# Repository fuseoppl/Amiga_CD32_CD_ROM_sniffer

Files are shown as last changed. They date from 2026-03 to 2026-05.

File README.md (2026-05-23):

# Amiga CD32 CD Drive sniffer and Track Display

* CD32 Akiko-CDROM IF command sniffer and track display
* Arduino pin 13 to Amiga CD32 IF_CLK
* Arduino pin 11 to Amiga CD32 IF_DATA
* Arduino pin  3 to Amiga CD32 IF_DIR
* Arduino GND    to Amiga CD32 GND
* Arduino pin  4 to Amiga CD32 RST via schottky diode, anode to CD32 RST
* The display must be with I2C communication!
* https://www.tztstore.com/goods/show-6267.html
* TZT 2.26 Inch 4PIN White OLED Screen Module IPS 1602 Character OLED Screen KS0066 Drive IC IIC Interface 5V For Arduino
* The display must be with I2C communication!

To work in display mode, leave this enabled:
#define LCDENABLE

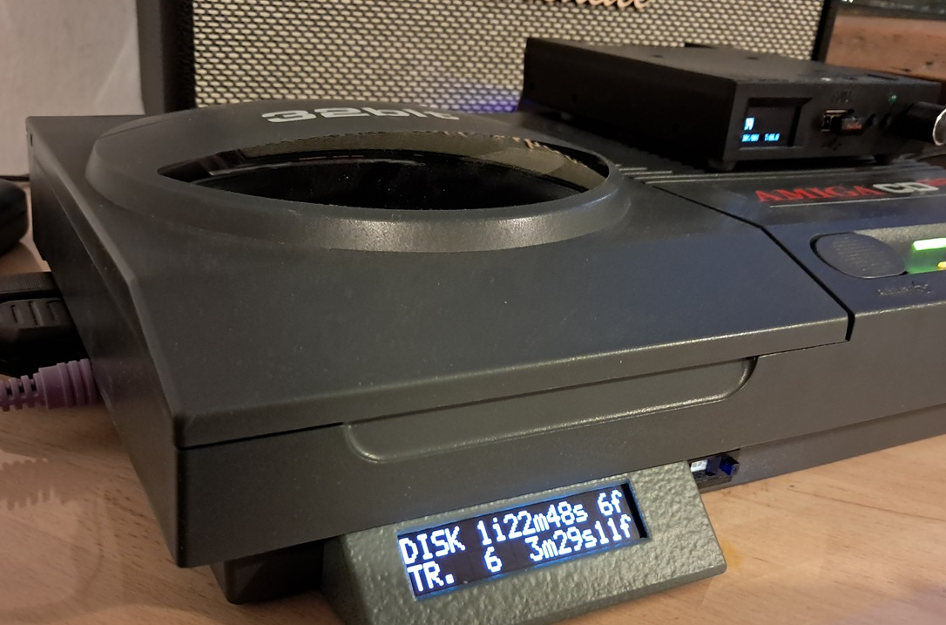
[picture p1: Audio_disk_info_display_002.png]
schema


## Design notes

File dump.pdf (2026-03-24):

TOC Information: | Audio CD Play Packets (first track)
LBA: 0 / 00:02:00 | 1 | 2 | 3 | 4 | 5 | 6 | 7 | 8 | 9 | 10 | 11 | 12 | 13 | 85 | 86 | Packets
Track | 01 | Audio | 03:27:31 | LBA: | 0 | 00:02:00 | 15

INITIALIZATION .

READ CONTENT .
Akiko | 26 | 36 | 46 | 56 | 66 | 76 | 86 | 96 | A6 | B6 | C6 | D6 | E6 | 36 | 46 | Low nibble always 0x6, High incrasing
Track | 02 | Audio | 03:29:34 | LBA: | 15556 | 03:29:31 | 0 | A | D9 | C9 | B9 | A9 | 99 | 89 | 79 | 69 | 59 | 49 | 39 | 29 | 19 | C9 | B9 | Checksum (2's complement)
Track | 03 | Audio | 04:23:03 | LBA: | 31265 | 06:58:65 | EA | A2

CD Drive

| | | | | | | | | | 26 | 36 | 46 | 56 | 66 | 76 | 86 | 96 | A6 | B6 | C6 | D6 | E6 | 36 | 46 | same as the first byte in the Akiko order
Track | 04 | Audio | 04:23:73 | LBA: | 50993 | 11:21:68 | N/A | | 6 | 2 | 2 | 2 | 2 | 2 | 2 | 2 | 2 | 2 | 2 | 2 | 2 | 2 | 2 | 2 | 2
Track | 05 | Audio | 03:33:04 | LBA: | 70791 | 15:45:66 | 27 | | A | 0 | 0 | 0 | 0 | 0 | 0 | 0 | 0 | 0 | 0 | 0 | 0 | 0 | 0 | 0 | 0 ?
Track | 06 | Audio | 04:00:17 | LBA: | 86770 | 19:18:70 | D8 | | 0 | 1 | 1 | 1 | 1 | 1 | 1 | 1 | 1 | 1 | 1 | 1 | 1 | 1 | 1 | 1 | 1 (WinUAE says: CtlAdr) ?
Track | 07 | Audio | 01:06:20 | LBA: | 104787 | 23:19:12 | 27 | | 1 | 1 | 1 | 1 | 1 | 1 | 1 | 1 | 1 | 1 | 1 | 1 | 1 | 1 | 1 | 1 | Track Nr
Track | 08 | Audio | 05:23:20 | LBA: | 109757 | 24:25:32 | 1 | | 0 | 1 | 1 | 1 | 1 | 1 | 1 | 1 | 1 | 1 | 1 | 1 | 1 | 1 | 1 | 1 | 1 (WinUAE says: Index) ?
Track | 09 | Audio | 04:34:08 | LBA: | 134002 | 29:48:52 | 43 C | 6 | 0 | 0 | 0 | 0 | 0 | 0 | 0 | 0 | 0 | 0 | 0 | 0 | 0 | 0 | 0 | Track.time.min (0-99)
Track | 10 | Audio | 04:25:60 | LBA: | 154560 | 34:22:60 | 48 H | 1 | 0 | 0 | 0 | 0 | 0 | 0 | 0 | 0 | 0 | 1 | 1 | 1 | 1 | 8 | 8 | Track.time.sec (0-59)
Track | 11 | Audio | 05:43:15 | LBA: | 174495 | 38:48:45 | 49 | I | 49 | 2 | 11 | 21 | 29 | 39 | 47 | 57 | 58 | 65 | 0 | 8 | 18 | 26 | 15 | 24 | Track.time.frame (0-75)
Track | 12 | Audio | 02:53:73 | LBA: | 200235 | 44:31:60 | 4E N | 42 | 0 | 0 | 0 | 0 | 0 | 0 | 0 | 0 | 0 | 0 | 0 | 0 | 0 | 0 | 0 | 0
Track | 13 | Audio | 05:09:04 | LBA: | 213283 | 47:25:58 | 4F O | 0 | 0 | 0 | 0 | 0 | 0 | 0 | 0 | 0 | 0 | 0 | 0 | 0 | 0 | 0 | 0 | Disk.time.min (0-99)
Track | 14 | Audio | 05:51:55 | LBA: | 236462 | 52:34:62 | 4E N | 19 | 2 | 2 | 2 | 2 | 2 | 2 | 2 | 2 | 2 | 3 | 3 | 3 | 3 | 10 | 10 | Disk.time.sec (0-59)
LeadOut (LBA: 262842 / 58:26:42) | 20 | 18 | 2 | 11 | 21 | 29 | 39 | 47 | 57 | 58 | 65 | 0 | 8 | 18 | 26 | 15 | 24 | Disk.time.frame (0-75)
| | | | | | | 20 | | 70 | 0 | 0 | 0 | 0 | 0 | 0 | 0 | 0 | 0 | 0 | 0 | 0 | 0 | 0 | 0 | 0
Track Information: | 4F 0 | 0 | 0 | 0 | 0 | 0 | 0 | 0 | 0 | 0 | 0 | 0 | 0 | 0 | 0 | 0 | 0 | 0
2D - | 0 | CE | A0 | 70 | 50 | 20 | F4 | C4 | B2 | 88 | 40 | 20 | F0 | C4 | 82 | 54 | Checksum (2's complement)
Track | 01 | LTSA: | 0 | LTS: | 15556 | 36 6 | BB
Track | 02 | LTSA: | 15556 | LTS: | 15709 | 35 5 | 65
Track | 03 | LTSA: | 31265 | LTS: | 19728 | 38 8 | 1 | Akiko to CD Drive
Track | 04 | LTSA: | 50993 | LTS: | 19798 | 2D - | 99 | Track number | A0=?, A1=Total Track number, A2=Total Disk Time
Track | 05 | LTSA: | 70791 | LTS: | 15979 | 32 2 | 6 | Strart time
Track | 06 | LTSA: | 86770 | LTS: | 18017 | 20 | A | Index ?
Track | 07 | LTSA: | 104787 | LTS: | 4970 | 32 2 | 0 | Checksum (2's complement)
Track | 08 | LTSA: | 109757 | LTS: | 24245 | 34 4 | 1 | Akiko order Checksum (2’s complement)
Track | 09 | LTSA: | 134002 | LTS: | 20558 | D4 | 0 | N/A = no ansfer from CD Drive
Track | 10 | LTSA: | 154560 | LTS: | 19935 | | 35 | | 6
Track | 11 | LTSA: | 174495 | LTS: | 25740 | 1 | 1 | SPI config for Arduino UNO
Track | 12 | LTSA: | 200235 | LTS: | 13048 | C9 | 49 | pinMode(MISO, OUTPUT);
Track | 13 | LTSA: | 213283 | LTS: | 23179 | N/A | 44 | // SPI on (MSTR = 0 so slave mode)
Track | 14 | LTSA: | 236462 | LTS: | 26380 | 44 | 0 | bitSet(SPCR, SPE);
0 | 19 | // SPI MODE 3
0 | 18 | bitSet(SPCR, CPOL);
0 | 70 | bitSet(SPCR, CPHA);
0 | 0 | // SPI LSB first
0 | 0 | bitSet(SPCR, DORD);
0 | B9 | // SPI interrupts on
3 | 75 | bitSet(SPCR, SPIE);
0 0
0 8A
0 6

### 0 A

| | | | | | | B8 | | 0
| | | | | | | 44 | | 1
| | | | | | | 1 | | 0
| | | | | | | BA | | 7
53 1
| | | | | | | AC | | 49
| | | | | | | 53 | | 45
| | | | | | | 29 | | 0
| | | | | | | 83 | | 23
| | | | | | | | | 19
| | | | | | | | | 12
| | | | | | | | | 0
| | | | | | | | | 0

A
85 1 79

6 A 0 1 0

7
1 49 46 0

23 19 12

0 0

9
95 0 6A

6 A 0 1 0

7
1 49 47 0

23 19 12

0 0

8
A5 1 59

6 A 0 1 0

8
1 49 48 0

24 25 32

0 0

D9

B5 0

4A6A01081

49 490

24 25

3200

D8
C51

396A01081

49 500

24 25

3200

D1
D50

2A6A01091

49 510

29 48

5200

87
E5

1
196A01091

49 520

29 48

5200

86

### F50A6A01091

49 530

29 48

5200

85
151

E96A010

101

49 540

34 22

6000

8A
250

DA

A 1 0

10
1 49 55 0

34 22 60

0 0

89
35 1 C9

6 A 0 1 0

10
1 49 56 0

34 22 60

0 0

88
45 0 BA

6 A 0 1 0

11
1 49 57 0

38 48 45

0 0

77
55 1 A9

A010

| 111

49 580

| 38 48
| 4500
| 76
| 650
| 9A6A010
| 111

49 590

| 38 48
| 4500
| 75
| 751
| 896A010
| 121

49 600

| 44 31
| 6000
| 5D
| 850 7A6

A

| 12
| 1 49 61 0
| 44 31 60
| 0 0
| 5C
| 95 1 69
| 6 A 0 1 0
| 12
| 1 49 62 0
| 44 31 60
| 0 0
| 5B
| A5 0 5A
| 6 A 0 1 0
| 13
| 1 49 63 0
| 47 25 58
| 0 0
| 6A
| B5 1 49
| 6 A

131

49 640

| 47 25
| 5800
| 69
| C50
| 3A6A010
| 131

49 650

| 47 25
| 5800
| 68
| D51
| 296A010
| 141

49 660

| 52 34
| 6200
| 42
| E50
| 1A6A0

49 67 0

52 34 62

0 0

41
F5 1 9

6 A 0 1 0

14
1 49 68 0

52 34 62

0 0

40
15 0 EA

6 A 0 1 0

A0
1 49 69 0

1
0 0 0 0

9A
25 1 D9

6 A 0 1

A0

70 0

1
0 0 0 0

93
35 0 CA

6 A 0 1 0

A0
1 49 71 0

1
0 0 0 0

92
45 1 B9

6 A 0 1 0

A1
1 49 72 0

14
0 0 0 0

7D
55 0 AA

6 A 0 1 0

A1

0
14
0 0 0 0

7C
65 1 99

6 A 0 1 0

A1
1 49 74 0

14
0 0 0 0

7B
75 0 8A

6 A 0 1 0

A2
1 50 0 0

58 26 42

0 0

3B
85 1 79

6 A 0 1 0

A2

58 26 42

0 0

3A
95 0 6A

6 A 0 1 0

A2
1 50 2 0

58 26 42

0 0

39
A5 1 59

6 A 0 1 0

1
1 50 3 0

0 2 0

0 0

97
B5 0 4A

6 A 0 1 0

1
1

4002000

96
C51

396A01011

505002000

95
D50

2A6A01021

50603

29
3100

38
E51

196A01021

50

31
0 0

37
F5 0 A

6 A 0 1 0

2
1 50 8 0

3 29 31

0 0

36
15 1 E9

6 A 0 1 0

3
1 50 9 0

6 58 65

0 0

CE
25 0 DA

6 A 0 1 0

3
1 50 10

0 0

C7
35 1 C9

6 A 0 1 0

3
1 50 11 0

6 58 65

0 0

C6
45 0 BA

6 A 0 1 0

4
1 50 12 0

11 21 68

0 0

ED
55 1 A9

6 A 0 1 0

4
1 50 13 0

0
EC
65 0 9A

6 A 0 1 0

4
1 50 14 0

11 21 68

0 0

EB
75 1 89

6 A 0 1 0

5
1 50 15 0

15 45 66

0 0

C3
85 0 7A

92
6D
92 3

6A
A5 0 5A

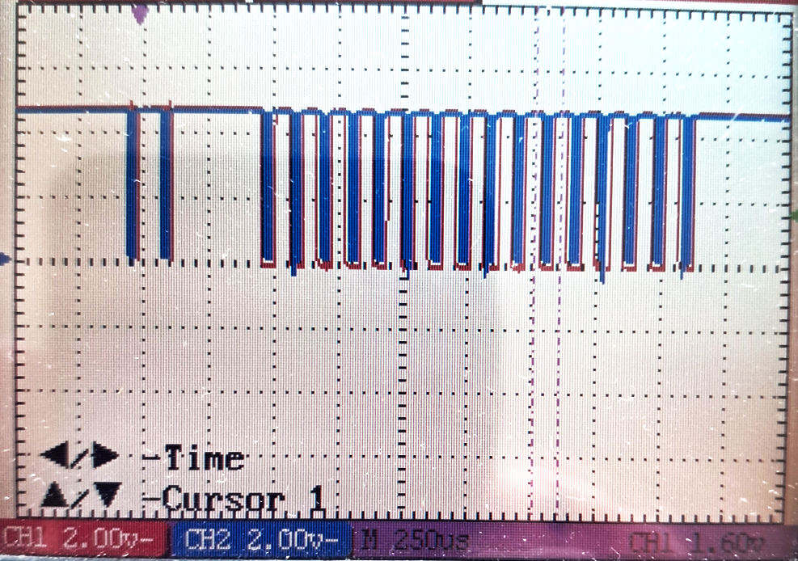
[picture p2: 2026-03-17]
Audio_PLAY_data_frame.png

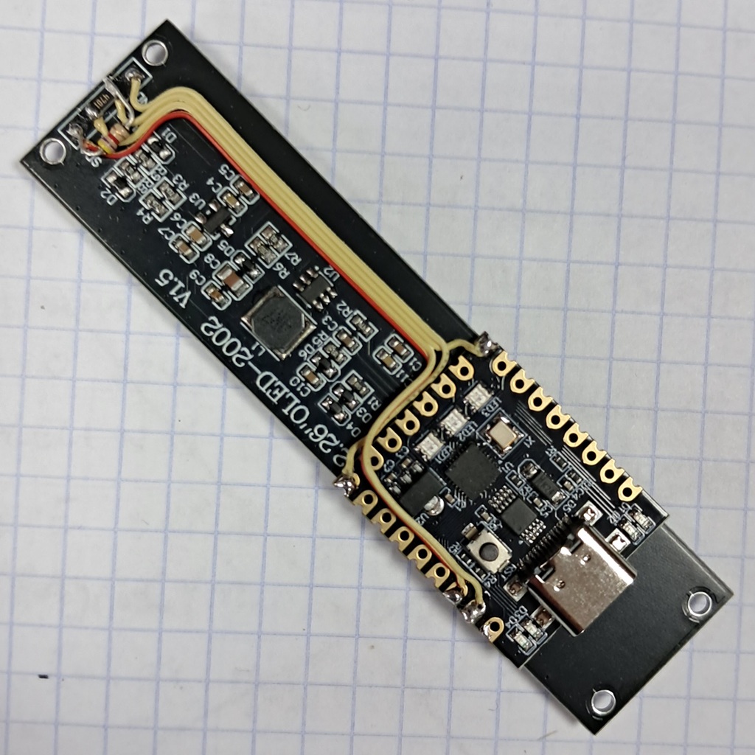
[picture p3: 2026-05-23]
Audio_disk_info_display-board.png

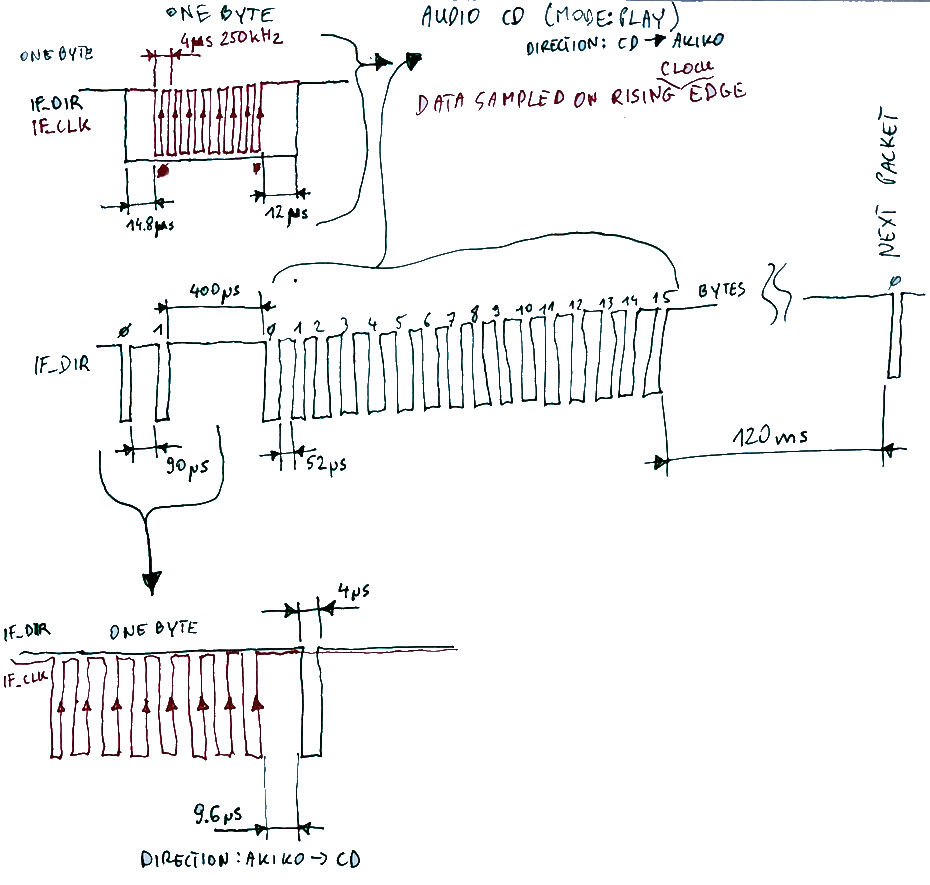
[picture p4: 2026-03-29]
IF_Signal_timing.png

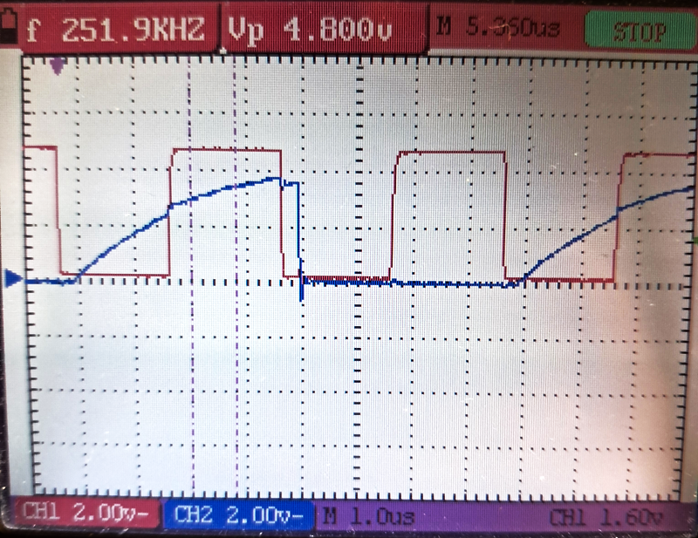
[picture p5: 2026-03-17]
IF_CLK_and_IF_DAT_signal.png

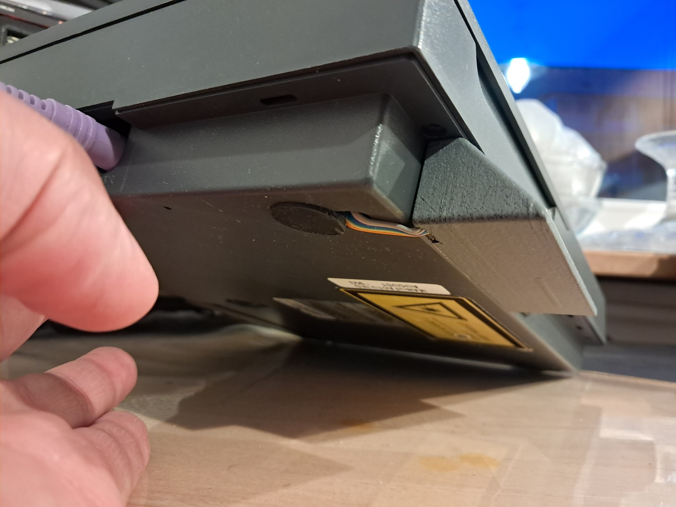
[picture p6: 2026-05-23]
Audio_disk_info_display_002_b.png

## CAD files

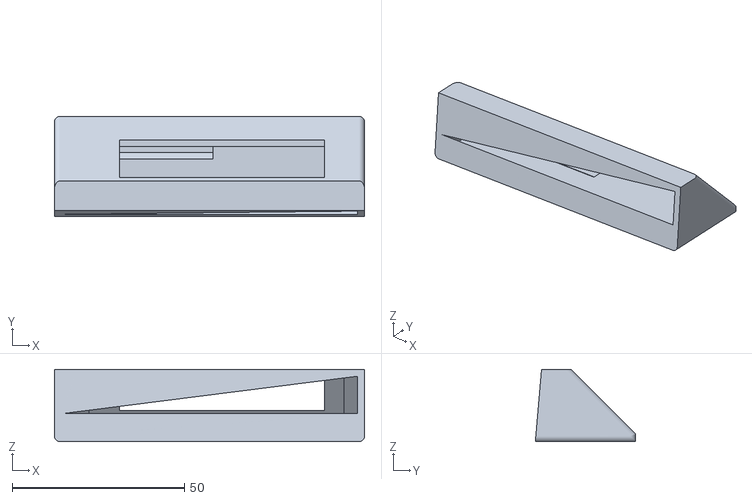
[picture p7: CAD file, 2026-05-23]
Time_Display_base.stl
90.0 x 29.1 x 21.0

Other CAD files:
Time_Display_base_pos.stl

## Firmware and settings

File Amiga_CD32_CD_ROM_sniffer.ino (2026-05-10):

//CD32 Akiko-CDROM IF command sniffer and track display
//Arduino pin 13 to Amiga CD32 IF_CLK
//Arduino pin 11 to Amiga CD32 IF_DATA
//Arduino pin  3 to Amiga CD32 IF_DIR
//Arduino GND    to Amiga CD32 GND
//Arduino pin  4 to Amiga CD32 RST via schottky diode, anode to CD32 RST
//The display must be with I2C communication!
//https://www.tztstore.com/goods/show-6267.html
//TZT 2.26 Inch 4PIN White OLED Screen Module IPS 1602 Character OLED Screen KS0066 Drive IC IIC Interface 3.3V For Arduino

//I was wondering why the CD drive has three microcontroller pins connected to handle the IF_DATA signal, and now it's all clear to me.
//The CD drive operates in MASTER mode.
//When the CD drive wants to send data to Akiko, it sets the IF_DIR signal to a logical 0.
//After about 15 µs, it transmits the data. This means it starts the clock on the IF_CLK signal, and on the rising edge of the clock signal, the IF_DATA signal is set accordingly.
//Nothing special, IF_DIR acts a bit like a chip select signal.
//The problem arises when Akiko needs to send data; it can't control the clock signal or the IF_DIR signal, as these are inputs to the Akiko.
//In this situation, it sets the IF_DATA pin to a logical 0. However, this doesn't provide any information for the SPI interface for the master device, such as the CD drive.
//So the third pin in the CD drive's microcontroller is simply an interrupt input, activated when there's no data transmission.
//After detecting a signal change on this pin, the CD drive's microcontroller enables the SPI interface and begins transmitting the clock signal.
//It all makes sense now, although in my opinion it was a poor solution, but that doesn't matter now, what matters is that in the microcontroller that will support the new CD drive,
//the MISO, MOSI and INT pins need to be connected together. 

const char* firmwareRevision = "3.6";

//Display on, sniffer off
#define LCDENABLE

#include "pins_arduino.h"

#if defined(LCDENABLE)
#include "OLedI2C.h"
OLedI2C lcd;
int contrast = 0xFF;
#endif

#define IF_DIR    3
//#define READY_OUT 4
volatile unsigned long start_time;
volatile uint8_t read_byte[255];
volatile bool IF_DIR_level[255];
volatile bool IF_DIR_int_occurred;
volatile uint8_t position;
volatile bool backgroundPrinted;
volatile bool frameRecived;

void setup (void)
{
  //pinMode(READY_OUT, OUTPUT);
  //digitalWrite(READY_OUT, LOW);

  pinMode(IF_DIR, INPUT);

  // have to send on master in, *slave out*
  pinMode(MISO, OUTPUT);
  pinMode(MOSI, INPUT);
  pinMode(SCK, INPUT);
  
  // SPI on (MSTR = 0 so slave mode)
  bitSet(SPCR, SPE);

  // SPI MODE 3
  bitSet(SPCR, CPOL);
  bitSet(SPCR, CPHA);

  // SPI LSB first
  bitSet(SPCR, DORD);

#if defined(LCDENABLE)
  lcd.init();
//  lcd.print("CD32");
#else
  Serial.begin (2000000);
#endif

  //digitalWrite(READY_OUT, HIGH);

  // SPI interrupts on
  bitSet(SPCR, SPIE);

  // clear interrupt register INT0
  //bitSet(EIFR, INTF0);
  // attach interrupt INT0
  attachInterrupt(digitalPinToInterrupt(IF_DIR), ISR1, RISING);
}

// here SPI Buffer, I have something
ISR (SPI_STC_vect)
{
  IF_DIR_level[position] = digitalRead(IF_DIR);
  
  read_byte[position] = SPDR;

  position++;
}

// here interrupt INT1, a change in the monitored signal occurred
void ISR1()
{
  start_time = millis();

// clear SPI buffer
// SPI off
  bitClear(SPCR, SPE);
// SPI on   
  bitSet(SPCR, SPE);

  IF_DIR_int_occurred = true;
}

// not needed, all you need is a change in the DORD SPI register
/*
byte reverseBits(byte x) {
  x = (x & 0xF0) >> 4 | (x & 0x0F) << 4;
  x = (x & 0xCC) >> 2 | (x & 0x33) << 2;
  x = (x & 0xAA) >> 1 | (x & 0x55) << 1;
  return x;
}
*/

uint8_t TwoComplementChecksum8(const byte *data, size_t dataLength, size_t startData)
{
  uint8_t value = 0;
  for (size_t i = startData; i < dataLength; i++)
  {
    value += (uint8_t)data[i];
  }
  return ~value;
}

void loop (void)
{
  // 1 ms have passed since the last change of the IF_DIR signal, maybe nothing will happen,
  // so we print the collected data
  if (IF_DIR_int_occurred && millis() > start_time + 1)
  {
    detachInterrupt(digitalPinToInterrupt(IF_DIR));
    bitClear(SPCR, SPIE);
    //noInterrupts();

#if defined(LCDENABLE)
    //Play packet
    if ((read_byte[0] & 0xF) == 0x6 && read_byte[1] == (uint8_t)~read_byte[0] && read_byte[2] == read_byte[0] && read_byte[4] == 0x0 && read_byte[11] == 0x0 && read_byte[15] == 0x0 && read_byte[16] == 0x0 && TwoComplementChecksum8(read_byte, 16, 2) == read_byte[17])
    {
      uint8_t playMode = read_byte[3]; //0x2 = Play, 0x3 = Pause

      frameRecived = true;

      String TN = String(read_byte[6], HEX);
      if (TN.length() == 1) TN = " " + TN;
      String TM = String(read_byte[8], HEX);
      if (TM.length() == 1) TM = " " + TM;
      String TS = String(read_byte[9], HEX);
      if (TS.length() == 1) TS = " " + TS;
      String TF = String(read_byte[10], HEX);
      if (TF.length() == 1) TF = " " + TF;
      String DX = String(read_byte[7], HEX);
      if (DX.length() == 1) DX = " " + DX;
      String DM = String(read_byte[12], HEX);
      if (DM.length() == 1) DM = " " + DM;
      String DS = String(read_byte[13], HEX);
      if (DS.length() == 1) DS = " " + DS;
      String DF = String(read_byte[14], HEX);
      if (DF.length() == 1) DF = " " + DF;

      lcd.setCursor(4,0);
      lcd.print(DX.c_str());
      lcd.setCursor(7,0);
      lcd.print(DM.c_str());
      lcd.setCursor(10,0);
      lcd.print(DS.c_str());
      lcd.setCursor(13,0);
      lcd.print(DF.c_str());

      lcd.setCursor(4,1);
      lcd.print(TN.c_str());
      lcd.setCursor(7,1);
      lcd.print(TM.c_str());
      lcd.setCursor(10,1);
      lcd.print(TS.c_str());
      lcd.setCursor(13,1);
      lcd.print(TF.c_str());
    }
    else
    {
#endif
      for (int i = 0; i < position; i++)
      {
#if defined(LCDENABLE)
        if (read_byte[i] == 0x27 && read_byte[i+1] == 0xD8 && read_byte[i+2] == 0x27 && read_byte[i+3] == 0x1)
        {
          String brandName = "";
          String modelName = "";

          for (int ib = i+4; ib < i+12; ib++)
          {
            brandName += (char)read_byte[ib];
          }

          for (int im = i+12; im < i+22; im++)
          {
            modelName += (char)read_byte[im];
          }

          lcd.setCursor(0,0);
          lcd.print(brandName.c_str());
          lcd.print("     ");
          lcd.print(firmwareRevision);
          lcd.setCursor(0,1);
          lcd.print(modelName.c_str());
          lcd.print("       ");

          frameRecived = false;
          backgroundPrinted = false;
        }
        else if (read_byte[i] == 0x6 && read_byte[i+1] == 0xA && read_byte[i+2] == 0x0 && read_byte[i+3] == 0x1 && read_byte[i+4] == 0x0 && read_byte[i+5] > 0x9F && TwoComplementChecksum8(read_byte, i+14, i) == read_byte[i+15])
        {
          frameRecived = true;

          if (read_byte[i+5] == 0xA0)
          {
            String DX = String(read_byte[i+6], HEX);
            if (DX.length() == 1) DX = " " + DX;

            lcd.setCursor(4,0);
            lcd.print(DX.c_str());
          }
          else if (read_byte[i+5] == 0xA1)
          {
            String TN = String(read_byte[i+10], HEX);
            if (TN.length() == 1) TN = " " + TN;

            lcd.setCursor(4,1);
            lcd.print(TN.c_str());
          }
          else if (read_byte[i+5] == 0xA2)
          {
            String DM = String(read_byte[i+10], HEX);
            if (DM.length() == 1) DM = " " + DM;
            String DS = String(read_byte[i+11], HEX);
            if (DS.length() == 1) DS = " " + DS;
            String DF = String(read_byte[i+12], HEX);
            if (DF.length() == 1) DF = " " + DF;

            lcd.setCursor(7,0);
            lcd.print(DM.c_str());
            lcd.setCursor(10,0);
            lcd.print(DS.c_str());
            lcd.setCursor(13,0);
            lcd.print(DF.c_str());

            lcd.setCursor(7,1);
            lcd.print("  ");
            lcd.setCursor(10,1);
            lcd.print("  ");
            lcd.setCursor(13,1);
            lcd.print("  ");
          }        
        }
#else
        Serial.print (i);
        Serial.print (";");
        Serial.print (IF_DIR_level[i]);
        Serial.print (";");
        Serial.println (read_byte[i], HEX);
#endif
      }
#if defined(LCDENABLE)
    }

    if (!backgroundPrinted && frameRecived)
    {
      lcd.setCursor(0, 0);
      lcd.print("DISK  i  m  s  f"); //index, minutes, seconds, frames
      lcd.setCursor(0, 1);
      lcd.print("TR.      m  s  f"); //track, minutes, seconds, frames

      backgroundPrinted = true;
    }
#endif

    position = 0;
    IF_DIR_int_occurred = false;
    memset(read_byte, 0, sizeof read_byte);

    attachInterrupt(digitalPinToInterrupt(IF_DIR), ISR1, RISING);
    bitSet(SPCR, SPIE);
    //interrupts();
  }
}

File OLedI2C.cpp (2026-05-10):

/*
This is my first Library to make writing to the OLED 1602
Display much easier, the display is based on the SSD1311.
The display has 16 characters and 2 lines.
The library is far from complete and may be prone to errors.
Feedback welcome, visit www.gadjet.co.uk
Phil Grant 2013
Scrolling contributed by Nathan Chantrell http://nathan.chantrell.net/

Updated 06/11/2013 to include the cursPos data in the sendString function
sendString("string", col, row)
*/
#include "OLedI2C.h" 
#include "Wire.h"
#define OLED_Address 0x3c
#define OLED_Command_Mode 0x80
#define OLED_Data_Mode 0x40

OLedI2C::OLedI2C(){}
OLedI2C::~OLedI2C(){}

void OLedI2C::init()
{
  // *** I2C initial *** //
  //delay(100);
  sendCommand(0x2A);	  // **** Set "RE"=1	00101010B
  sendCommand(0x71);
  sendCommand(0x5C);
  sendCommand(0x28);

  sendCommand(0x08);	  // **** Set Sleep Mode On
  sendCommand(0x2A);	  // **** Set "RE"=1	00101010B
  sendCommand(0x79);	  // **** Set "SD"=1	01111001B

  sendCommand(0xD5);
  sendCommand(0x70);
  sendCommand(0x78);	  // **** Set "SD"=0  01111000B

  sendCommand(0x08);	  // **** Set 5-dot, 3 or 4 line(0x09), 1 or 2 line(0x08)

  sendCommand(0x06);	  // **** Set Com31-->Com0  Seg0-->Seg99

  // **** Set OLED Characterization *** //
  sendCommand(0x2A);  	// **** Set "RE"=1 
  sendCommand(0x79);  	// **** Set "SD"=1

  // **** CGROM/CGRAM Management *** //
  sendCommand(0x72);  	// **** Set ROM
  sendCommand(0x00);  	// **** Set ROM A and 8 CGRAM


  sendCommand(0xDA); 	  // **** Set Seg Pins HW Config
  sendCommand(0x10);   

  sendCommand(0x81);  	// **** Set Contrast
  sendCommand(0xFF); 

  sendCommand(0xDB);  	// **** Set VCOM deselect level
  sendCommand(0x30);  	// **** VCC x 0.83

  sendCommand(0xDC);  	// **** Set gpio - turn EN for 15V generator on.
  sendCommand(0x03);

  sendCommand(0x78);  	// **** Exiting Set OLED Characterization
  sendCommand(0x28); 
  sendCommand(0x2A); 
  //sendCommand(0x05); 	// **** Set Entry Mode
  sendCommand(0x06); 	  // **** Set Entry Mode
  sendCommand(0x08);  
  sendCommand(0x28); 	  // **** Set "IS"=0 , "RE" =0 //28
  sendCommand(0x01); 
  sendCommand(0x80); 	  // **** Set DDRAM Address to 0x80 (line 1 start)

  delay(1); //100
  sendCommand(0x0C);  	// **** Turn on Display
}
 
void OLedI2C::setCursor(uint8_t col, uint8_t row)
{
  int row_offsets[] = { 0x00, 0x40 };
  sendCommand(0x80 | (col + row_offsets[row]));
}
 
void OLedI2C::clearLcd()
{
  sendCommand(0x01);
}

void OLedI2C::lcdOff()
{
  sendCommand(0x08);  	// **** Turn on Off
}

void OLedI2C::lcdOn()
{
  sendCommand(0x0C);  	// **** Turn on On
}

void OLedI2C::sendCommand(unsigned char command)
{
  Wire.beginTransmission(OLED_Address);  // **** Start I2C 
  Wire.write(OLED_Command_Mode);     		 // **** Set OLED Command mode
  Wire.write(command);
  Wire.endTransmission();                // **** End I2C 
  delay(10);
}
void OLedI2C::sendFloat(float digit, uint8_t dec, uint8_t nad, uint8_t col, uint8_t row)
{
  char line[10];//Ten characters, I hope that's enough
  dtostrf(digit,dec,nad,line);//Convert the float value to a string
  sendString(line, col, row);
}

 void OLedI2C::setContrast(unsigned char contrast) // contrast as 0x00 to 0xFF
{
  //Set OLED Command set
	sendCommand(0x2A); 
	sendCommand(0x79); 
	
	sendCommand(0x81);      // Set Contrast
	sendCommand(contrast);  // send contrast value
	sendCommand(0x78);      // Exiting Set OLED Command set
  sendCommand(0x28);
}

void OLedI2C::sendString(const char *String, uint8_t col, uint8_t row)
{
  setCursor(col, row);
  unsigned char i=0;
  while(String[i])
  {
    sendData(String[i]);  // *** Show String to OLED
    i++;
  }
}

void OLedI2C::print(const char *String)
{
  unsigned char i=0;
  while(String[i])
  {
    sendData(String[i]);  // *** Send String to OLED
    i++;
  }
}

void OLedI2C::sendData(unsigned char data)
{
  Wire.beginTransmission(OLED_Address);   // **** Start I2C 
  Wire.write(OLED_Data_Mode);             // **** Set OLED Data mode
  Wire.write(data);
  Wire.endTransmission();                 // **** End I2C 
}
void OLedI2C::scrollString(char* message, byte row, unsigned int time)//written by Nathan Chantrell http://nathan.chantrell.net/
{ 
  char buffer[16];
  for (byte i=0;i<strlen(message)+16;i++)
  {
    byte pos = i+1;
    for (byte j=0;j<16;j++)
    {
      if ((pos<16)||(pos>strlen(message)+15))
      { // pad and trail with blank spaces
        buffer[j]=' ';
      }
      else buffer[j]=message[pos-16];
      pos++;
    }
    sendString(buffer, 0, row);
    delay(time);
  }
}

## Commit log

2026-03-19 dump update
    [dump.ods]
2026-03-21 Added I2C display support for displaying track number and duration on an audio CD
2026-03-22 v.2.0 display total disk time, update dump
    [dump.ods]
2026-05-23 case update
    [Time_Display_base.stl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]
